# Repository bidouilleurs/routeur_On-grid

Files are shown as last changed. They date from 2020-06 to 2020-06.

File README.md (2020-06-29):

# routeur_On-grid

Version du routeur DC modifié avec 1 diode pour connaitre le sens du transfert de puissance ( sens du courant ) 

-les entrées de la pince DC sont utilisées pour raccorder des pinces AC ( 30A, 1V) 

-la régulation se fait sur le courant inverse (injection) règlé avec le tolérance-négative 

-sur la page web il faut lire Le Courant AC dans intensité batterie 

-la fonction relais statique et thermostat sont inversé si la température du ballon descent en dessous d'une valeur, le relais s'enclenche 

-on pourra donc l'associer au relais Heures creuses pour maintenir la température si le soleil n'est pas au rendez-vous 

-Les informations MQTT restent identiques

Fichiers modifiés du routeur off-grid

source.ino

triac.cpp ( tient compte de la diode ) 

mesure.cpp et .h

regulation.cpp et .h

plus de simulation.cpp

le reste est identique

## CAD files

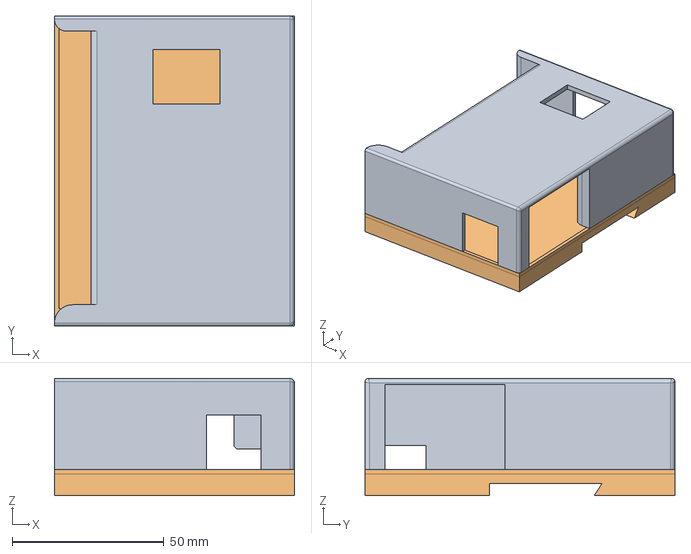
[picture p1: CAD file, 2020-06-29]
Hardware/routeurre3.FCStd
79.0 x 102.0 x 38.5 mm
Pocket001Body

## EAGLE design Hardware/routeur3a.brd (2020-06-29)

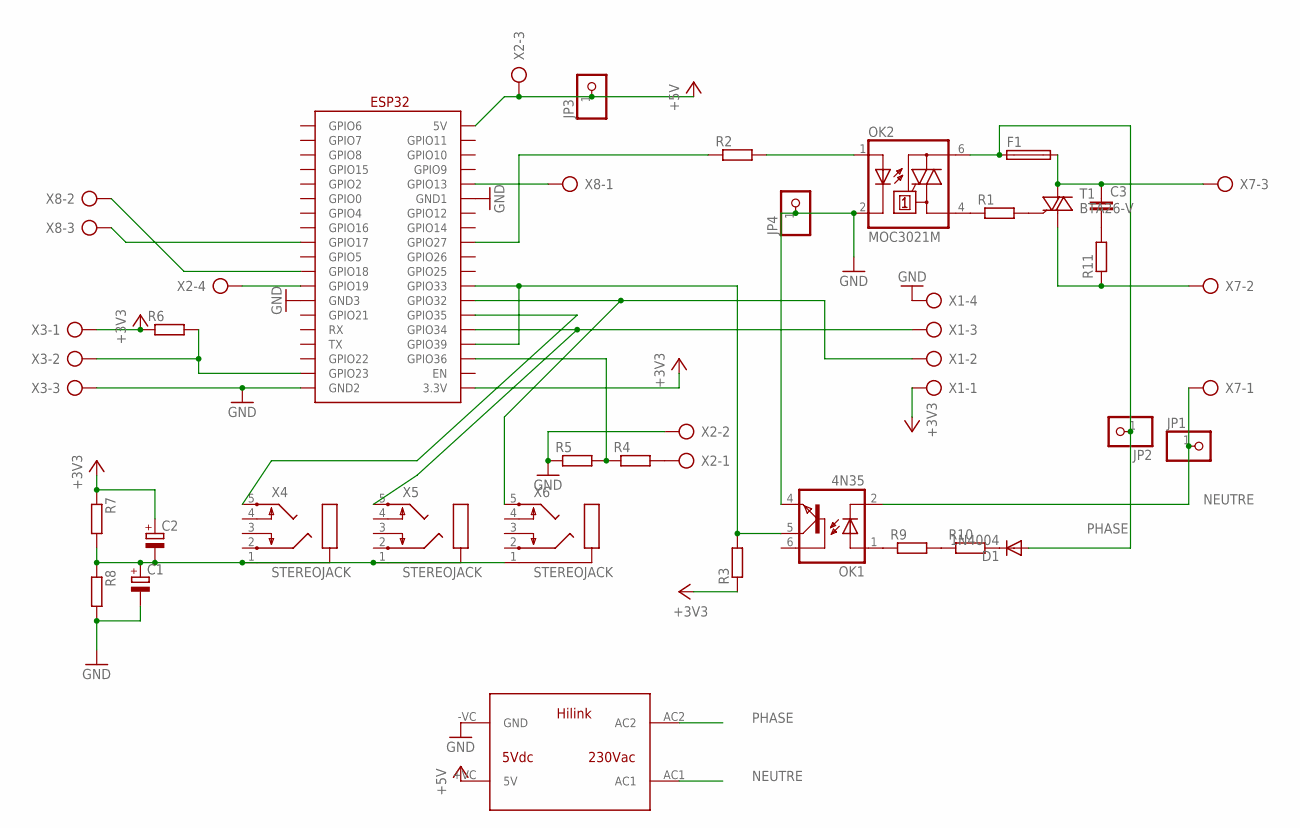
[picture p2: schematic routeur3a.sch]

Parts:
C1, C2: CPOL-EUE5-8.5; E5-8,5
C3: C-EU150-072X183; C150-072X183
D1: 1N4004; DO41-10
F1: 19560
JP1, JP2, JP3, JP4: PINHD-1X1; 1X01
OK1: 4N35; DIL06
OK2: MOC3021M; DIL06
R1, R9, R10: R-EU_0207/10; 0207/10
R2, R3, R4, R5, R6, R7, R8: R-EU_R1206; R1206
R11: R-EU_0817/22; P0817/22
T1: BTA26-V; TOP3S-1
U$1: WEMOSD1ESP32; WEMOS-D1-MINI
U$2: HILINK
X1, X2: AK500/4
X3, X7, X8: AK500/3
X4, X5, X6: STEREOJACK; STX3100

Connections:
+3V3: C2.+, R3.1, R6.1, R7.1, U$1.3V3 (3.3V), X1.1, X3.1
+5V: JP3.1, U$1.VCC (5V), U$2.+VC (5V), X2.3
GND: C1.-, JP4.1, OK1.4 (EMI), OK2.2 (C), R5.1, R8.2, U$1.GND (GND1), U$1.GND2, U$1.GND3, U$2.-VC (GND), X1.4, X2.2, X3.3
unnamed: OK2.4 (A1), R1.1
unnamed: OK2.1 (A), R2.2
unnamed: R4.2, X2.1
unnamed: R1.2, T1.G
unnamed: C3.1, F1.2, T1.A2, X7.3
unnamed: R11.1, T1.A1, X7.2
unnamed: OK1.1 (A), R9.1
unnamed: R9.2, R10.1
unnamed: U$1.TCK (GPIO13), X8.1
unnamed: D1.C, R10.2
unnamed: C1.+, C2.-, R7.2, R8.1, X4.1, X5.1, X6.1
unnamed: C3.2, R11.2
unnamed: U$1.35 (GPIO35), X4.5
NEUTRE: JP1.1, OK1.2 (C), U$2.AC1, X7.1
PHASE: D1.A, F1.1, JP2.1, OK2.6 (A2), U$2.AC2
PINCE: U$1.32 (GPIO32), X1.2, X6.5
PINCEREF: U$1.34 (GPIO34), X1.3, X5.5
PZEMRX: U$1.17 (GPIO17), X8.3
PZEMTX: U$1.18 (GPIO18), X8.2
RELAIS: U$1.19 (GPIO19), X2.4
TEMP: R6.2, U$1.23 (GPIO23), X3.2
TENSION: R4.1, R5.2, U$1.SVP (GPIO36)
TRIAC: R2.1, U$1.27 (GPIO27)
ZC: OK1.5 (COL), R3.2, U$1.33 (GPIO33), U$1.SUN (GPIO39)

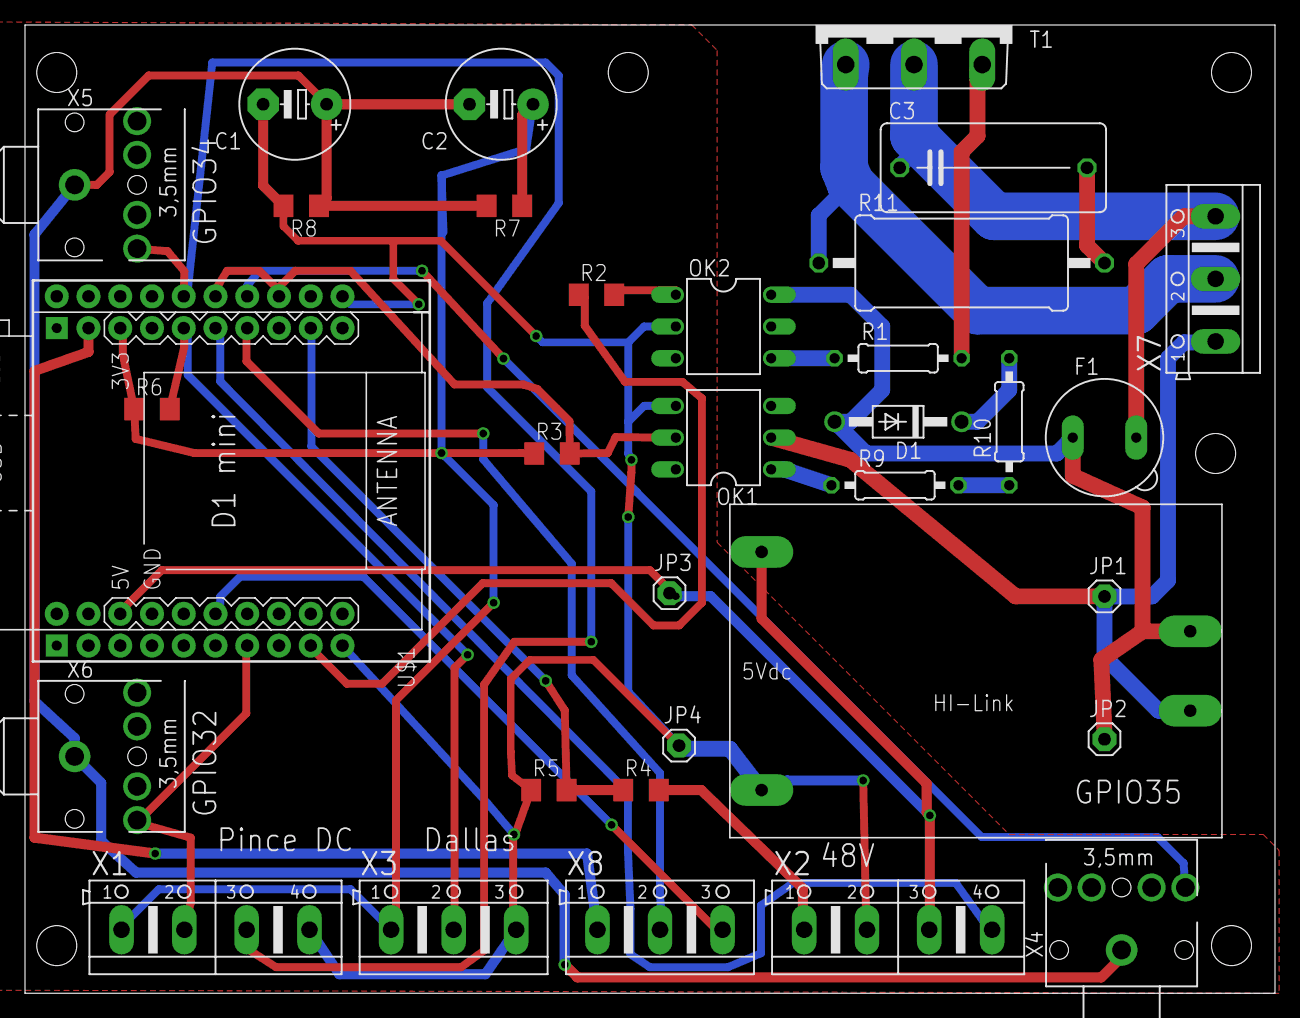
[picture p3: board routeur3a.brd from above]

Board: 2 copper layers, 100.0 x 77.5 mm, 33 parts (0 on the bottom side), 27 nets.

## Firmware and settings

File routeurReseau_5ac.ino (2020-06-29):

//**************************************************************/
// L'équipe de bidouilleurs discord reseautonome vous présente
// la réalisation d'un gradateur pour chauffe-eau en off grid
// gradateur synchronisé sur la production photovoltaique
// sans tirage sur les batteries pour utiliser le surplus dans
// un ballon d'eau chaude
//**************************************************************/

const char *version_soft = "Version 1.5 AC-DC avec 1 diode ZC"  ;

//**************************************************************/
// Initialisation
//**************************************************************/
#include "settings.h"
struct param routeur;
const int zeroc = 33;            // GPIO33  passage par zéro de la sinusoide
const int pinTriac = 27;         // GPIO27 triac
// analogique
const int pinPince = 32;         // GPIO32   pince effet hall
const int pinPinceAC = 32;         // GPIO32   pince effet hall
const int pinPinceACref = 39;    // GPIO39   ref tension pour pince AC 30A/1V
const int pinPinceRef = 34;      // GPIO34   pince effet hall ref 2.5V
const int pinPotentiometre = 35; // GPIO35   potentiomètre
const int pinTension = 36;       // GPIO36   capteur tension
const int pinTemp = 23;          // GPIO23  capteurTempérature
const int pinSortie2 = 13;       // pin13 pour  2eme "gradateur utilisée pour synchroniser le ZéroCrossing
const int pinRelais = 19;        // Pin19 pour sortie relais


bool marcheForcee = false;
short int marcheForceePercentage = 25;
short int sortieActive = 1;
unsigned long temporisation = 60;
float intensiteBatterie = 0;
float capteurTension = 0;
int puissanceGradateur = 0;
float temperatureEauChaude = 0;
float puissanceDeChauffe = 0;
float puissanceAC = 0;
float intensiteAC = 0;
bool etatRelaisStatique = false;
bool modeparametrage = false;

int resetEsp = 0;
int testwifi = 0;
int choixSortie = 0;
int paramchange = 0;
bool SAP = false;
bool MQTT = false;
bool serverOn = false;

/**********************************************/
/********** déclaration des librairiess *******/
/**********************************************/
#include "triac.h"

#ifdef WifiMqtt
#include "modemqtt.h"
#endif

#ifdef WifiServer
#include "modeserveur.h"
#endif

#ifdef EEprom
#include "prgEEprom.h"
#endif

#ifdef EcranOled
#include "afficheur.h"
#endif

#ifdef Bluetooth
#include "modeBT.h"
#endif

//#define simulation // utiliser pour faire les essais sans les accessoires
#ifdef simulation
#include "simulation.h"
#endif

#include "mesure.h"
#include "regulation.h"

/***************************************/
/******** Programme principal   ********/
/***************************************/
void setup()
{

  Serial.begin(115200);

  pinMode(pinTriac, OUTPUT);  digitalWrite(pinTriac, LOW); // mise à zéro du triac au démarrage
  pinMode(pinSortie2, OUTPUT);  digitalWrite(pinSortie2, LOW); // mise à zéro du triac de la sortie 2
  pinMode(pinRelais, OUTPUT);  digitalWrite(pinRelais, HIGH); // mise à zéro du relais statique
  pinMode(zeroc,INPUT);
  pinMode(pinTemp, INPUT);
  pinMode(pinTension, INPUT);
  pinMode(pinPotentiometre, INPUT);
  pinMode(pinPince, INPUT);
  pinMode(pinPinceRef, INPUT);
  pinMode(pinPinceACref, INPUT);
  Serial.println();
  Serial.println(F("definition ok "));
  Serial.println(version_soft);
  Serial.println();

#ifdef EcranOled
  RAAfficheur.setup();
#endif


#ifdef EEprom
  RAPrgEEprom.setup();
#endif

  delay(500);
  marcheForcee = false; // mode forcé retirer au démarrage
  marcheForceePercentage = false;
  temporisation = 0;
  
#ifdef WifiMqtt
  RAMQTT.setup();
#endif

#ifdef WifiServer
  RAServer.setup(); // activation de la page Web de l'esp
#endif

#ifdef Bluetooth // bluetooth non autorise avec serveur web ou MQTT
  RABluetooth.setup();
#endif

#ifdef EcranOled
  RAAfficheur.setup();
#endif

#ifdef MesureTemperature
  RAMesure.setup();
#endif

#ifdef Pzem04t
  Serial2.begin(9600, SERIAL_8N1, RXD2, TXD2); // redefinition des broches du serial2
#endif

#ifdef parametrage
  modeparametrage = true;
#endif

#ifdef relaisPWM
  ledcAttachPin(pinRelais, 0); // broche 18, canal 0.
  ledcSetup(0, 5000, 10); // canal = 0, frequence = 5000 Hz, resolution = 10 bits 1024points
#endif


  delay(500);
  RATriac.watchdog(0);       // initialise le watchdog
  RATriac.start_interrupt(); // demarre l'interruption de zerocrossing et du timer pour la gestion du triac

}

int iloop = 0; // pour le parametrage par niveau


void loop()
{
  RATriac.watchdog(1);                  //chien de garde à 4secondes dans timer0
    RAMesure.mesureTemperature(); // mesure la temperature sur le ds18b20
    RAMesure.mesure_puissance();  // mesure la puissance sur le pzem004t
    intensiteBatterie=RAMesure.mesurePinceAC(pinPinceAC,0.350,true);

    RARegulation.pilotage();
     if (!marcheForcee) 
        {
          puissanceGradateur = RARegulation.regulGrad(-routeur.toleranceNegative,5,5,5);
         }
  
  // affichage traceur serie
 float c = puissanceGradateur;
  Serial.print(" ");
  Serial.print(c / 100);
   Serial.print(',');
  Serial.print(intensiteAC);
   Serial.print(',');
  Serial.println(-0.2);
 /* Serial.print(',');
  Serial.print(routeur.seuilDemarrageBatterie / 5);
  Serial.print(',');
  Serial.print(capteurTension / 5);
  Serial.print(',');
  Serial.println(-routeur.toleranceNegative);
*/
//  Serial.print(',');
//  Serial.print(intensiteAC) );
//  Serial.print(',');
//  Serial.println(puissanceAC/100);

//RAMesure.mesurePinceAC(pinPince,0.321,false);
//puissanceGradateur=300;

#ifdef relaisPWM
  ledcWrite(0, long(puissanceGradateur*1024/1000));  //  canal = 0, rapport cyclique = 
#endif

#ifdef EcranOled
 RAAfficheur.affichage_oled(); // affichage de lcd
#endif

#ifdef WifiMqtt
  RAMQTT.loop();
#endif

#ifdef WifiServer
  RAServer.loop();
  RAServer.coupure_reseau();
#endif


#ifdef EEprom
  
  if (resetEsp == 1)
  {
    RATriac.stop_interrupt();
    RAPrgEEprom.close_param(); 
    delay(5000);
  }
#endif

  if (resetEsp == 1)
  {
    Serial.println("Restart !");
    ESP.restart(); // redemarrage
  }
}

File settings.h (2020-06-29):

#ifndef RA_SETTINGS_H
#define RA_SETTINGS_H
/**********************************************/
/********** Liste des options possibles ******/
/********************************************/
//#define parametrage // utiliser pour faire les essais sans les accessoires

//**** options MINI ****
#define EcranOled         // si pas d'écran oled      installer librairie heltec dev board
#define MesureTemperature // capteur DS18B20       installer librairie dallas temperature
#define WifiServer // affiche les mesures dans une page html crée un point d'accès si pas de reseau
//#define WifiMqtt   // mettre en commentaire si pas de réseau       installer librairie ArduinoJson et PubSubClient
//#define WifiSAPServeur // autorise le point d'accès si pas de reseau

//**** options MAXI  ****
#define F50HZ // Frequence du reseau 50Hz ou 60Hz non testé
//#define CourantAClimite 0.5  // Courant d'entrée alternatif pour arrêter le routeur si l'onduleur recharge les batteries sur le reseau
//#define relaisPWM   // convertit le gradateur en signal PWM sur la pin relais

struct param
{
  float   zeropince           = -0.0;           // valeur mesurer à zéro (2) 2819 2818.5
  float   coeffPince          = 1 ;         // Calculer le coefficient (4)0.14 0.210
  float   coeffTension        = 0.018293;       // diviseur de tension
   float seuilDemarrageBatterie = 56;                    // seuil de mise en marche de la regulation dans le ballon
    float toleranceNegative = 0.5;                        // autorisation de 300mA négative au moment de la charge complète
    bool utilisation2Sorties = false;                      // validation de la sortie 2eme gradateur
    float temperatureBasculementSortie2 = 60;             // température pour démarrer la regul sur la sortie 2
    float temperatureRetourSortie1 = 45;                  // température pour rebasculer sur le premier gradateur
    bool relaisStatique = false;                          // Indique si un relais statique est utilisé
    float seuilMarche = 50;                               // température ou tension de déclenchement du relais
    float seuilArret = 45;                                // température ou tension de déclenchement du relais
    char tensionOuTemperature[2] = "V";                   // Indique si le seuil est en Volts ou en Degrés
    char ssid[30] = "livebox_";                      // ssid de la box internet
    char password[50] = "*******"; // mot de passe
                                                          // en mode serveur l'ip est 192.168.4.1'
                                                          // ssid , "routeur_esp32"
                                                          // password , "adminesp32"
    char mqttServer[30] = "192.168.1.28";
    short int mqttPort = 1883;
    char mqttUser[30] = "mosquittouser";
    char mqttPassword[50] = "azerty";
    char mqttopic[30] = "routeur/solar";
    char mqttopicInput[30] = "routeur/isolar";
    char mqttopicParam1[30] = "routeur/solar1";
    char mqttopicParam2[30] = "routeur/solar2";
    char mqttopicParam3[30] = "routeur/solar3";
    char mqttopicPzem1[30] = "routeur/Pzem1";
    float correctionTemperature = -2.3;
    char basculementMode[2] = "T"; // Choix du mode de basculement : T->température, P-> Puissance zero
};
extern struct param routeur; //  regroupe tous les parametres de configuration
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
